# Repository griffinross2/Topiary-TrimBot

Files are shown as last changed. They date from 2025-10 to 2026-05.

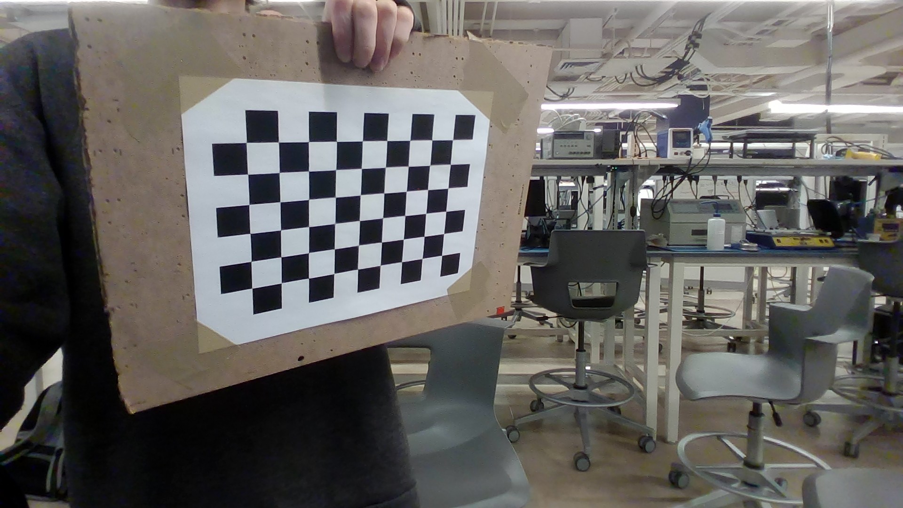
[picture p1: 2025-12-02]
experimental/cpp/plant_detect/images/WIN_20251111_21_14_00_Pro.jpg

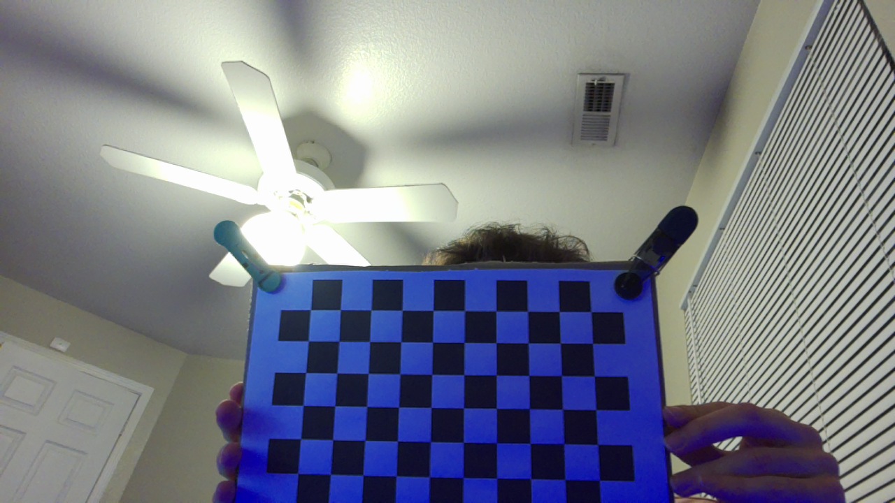
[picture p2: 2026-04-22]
experimental/cpp/plant_detect/images/pi/cal_10.jpg

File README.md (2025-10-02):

# Topiary TrimBot
Have you ever seen a sculpture made not of stone or ice, but a living, growing plant? Topiaries are a common feature of lavish gardens staffed by professional topiarists, but are often out-of-reach of the amateur gardener or homeowner. Enter the Topiary TrimBot, an automated platform for creating your own custom topiaries. A bush is placed in the machine and then the user inputs their desired 3D shape. The TrimBot will then automatically detect the current plant shape, generate a plan for trimming it into the desired shape, and perform the required cutting. The user can then practice maintaining and refining the shape via hand-trimming, helping them to learn the art of topiary!

This is the home of the Purdue University ECE 49595SD senior design group E11 in Fall 2025.

## Members
Griffin Ross - [GitHub](https://github.com/griffinross2) - [LinkedIn](https://www.linkedin.com/in/griffin-ross-eng/)

Thomas Schorer - [GitHub](https://github.com/ThomasSchorer) - [LinkedIn](https://www.linkedin.com/in/thomas-schorer/)

Jackson Duke - [GitHub](https://github.com/JDuke3) - [LinkedIn](https://www.linkedin.com/in/duke-jackson/)

Collin Shanks - [GitHub](https://github.com/collinshanks) - [LinkedIn](https://www.linkedin.com/in/collinshanks/)

## Documents
The docs/ folder contains documents grouped by category

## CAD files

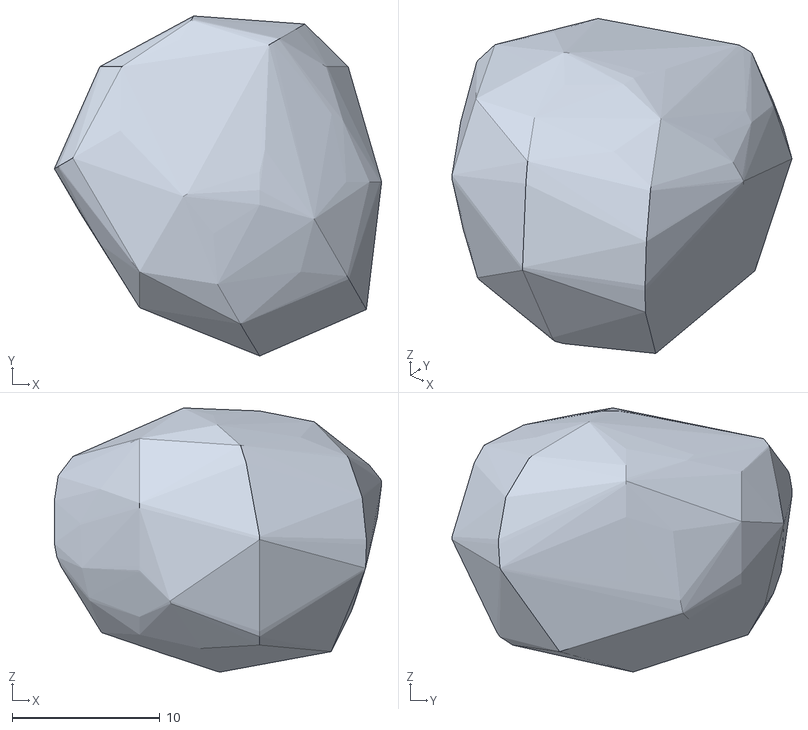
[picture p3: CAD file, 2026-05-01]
software/meshes/plant.ply
22.1 x 23.0 x 17.8

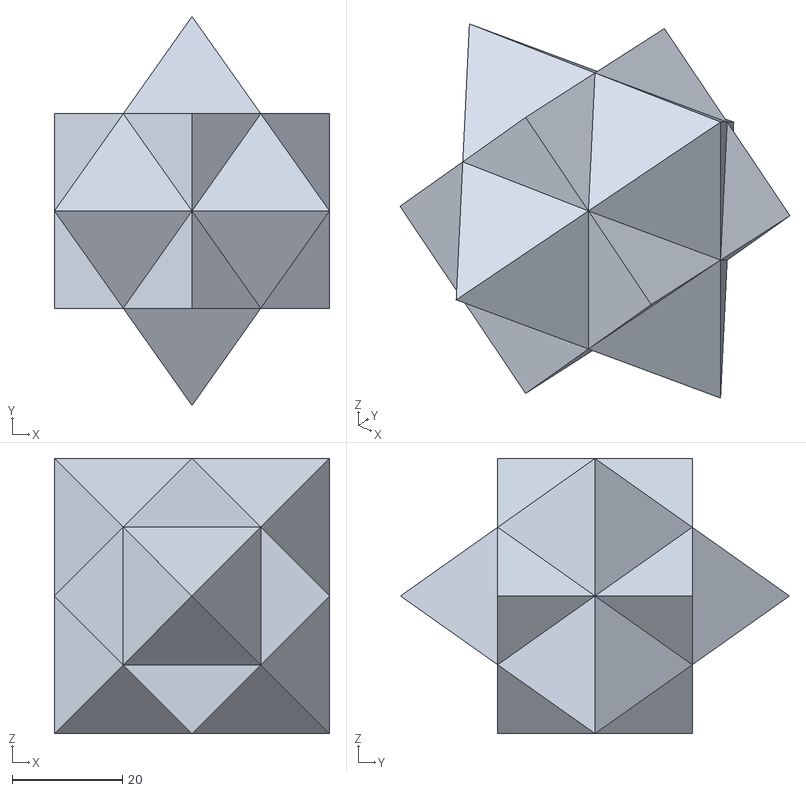
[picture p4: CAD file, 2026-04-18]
software/cube-octahedron-compound.stl
50.0 x 70.7 x 50.0

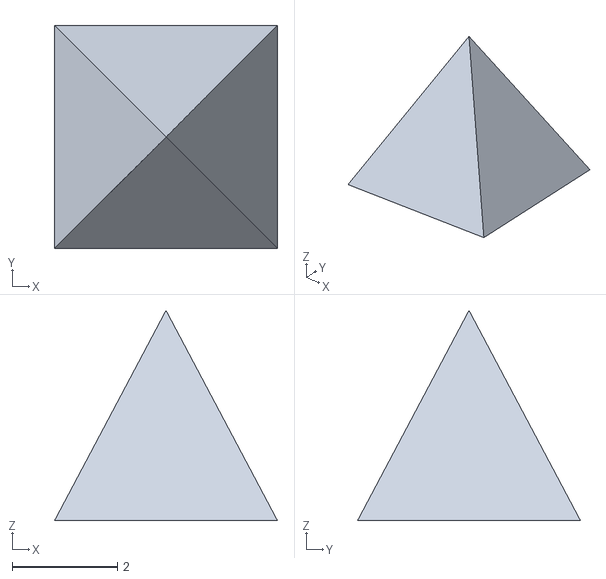
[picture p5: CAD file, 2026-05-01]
software/meshes/pyramid.stl
4.24 x 4.24 x 4.00

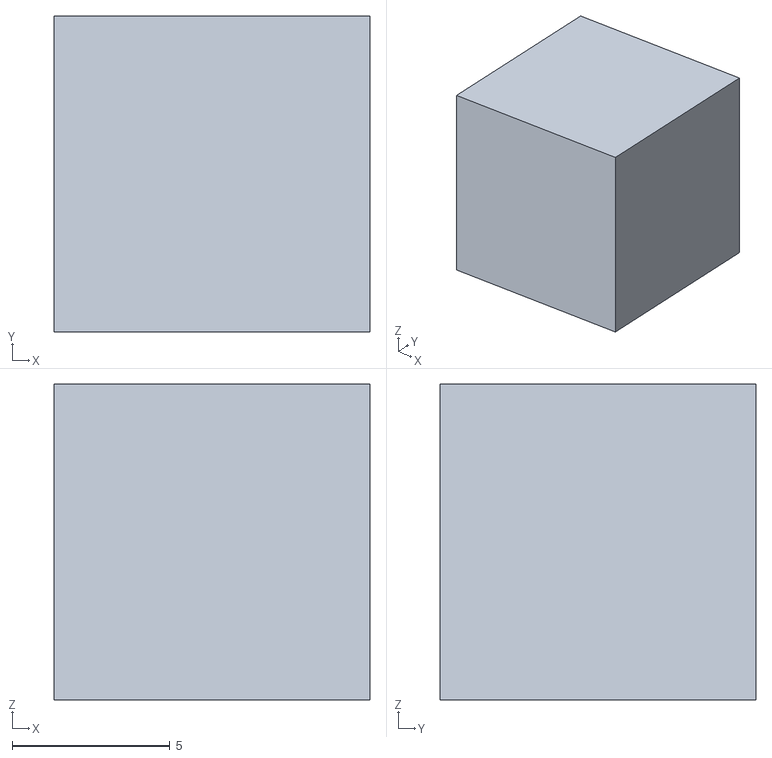
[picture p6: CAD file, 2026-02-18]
software/cube.obj
10.0 x 10.0 x 10.0

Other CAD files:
software/meshes/cube.obj

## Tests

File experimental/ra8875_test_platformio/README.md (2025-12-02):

# LCD Prototyping Project

This PlatformIO project is used to prototype LCD functionality on the STM32F469 Discovery Kit.

## How to use:

1. Install platformio on VSCode
2. Install python
3. Install STM Cube Programmer
4. Open the project in VSCode
5. In the root directory (with platformio.ini), add a script called `upload.bat` that will call STM Cube Programmer on the command line. 

## Upload.bat contents:

```
path/to/STM32_Programmer_CLI.exe -c port=SWD -el path/to/MT25QL128A_STM32F469I-DK.stldr" -d .pio/build/default/firmware.elf -rst
```

The path to STM32 Cube Programmer is usually: 

```
"C:\Program Files\STMicroelectronics\STM32Cube\STM32CubeProgrammer\bin\STM32_Programmer_CLI.exe"
```

and the path to the loader file is usually: 

```
"C:\Program Files\STMicroelectronics\STM32Cube\STM32CubeProgrammer\bin\ExternalLoader\MT25QL128A_STM32F469I-DK.stldr"
```

The second path is to an external loader file, which allows STM Cube Programmer to program external flash memories connected to the QSPI.

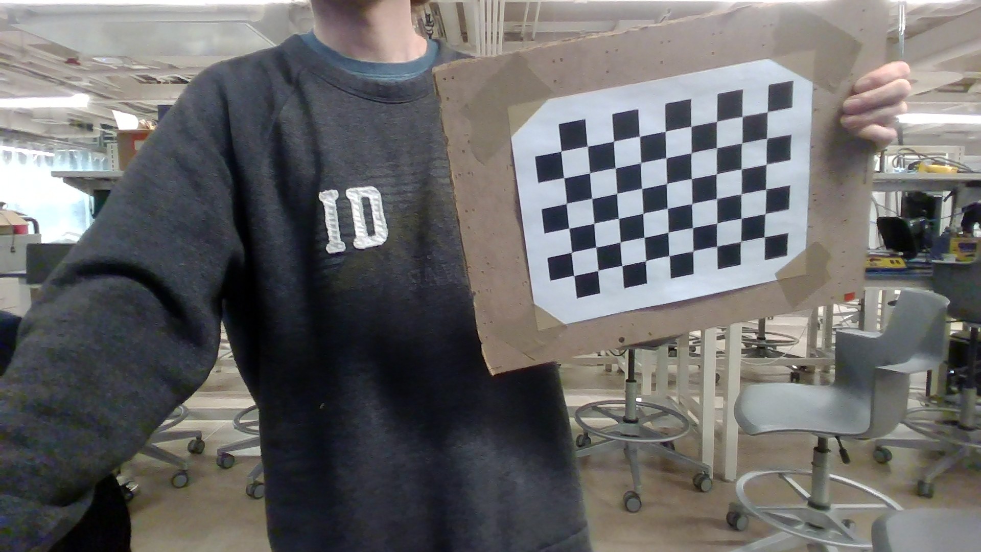
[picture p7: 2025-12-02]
experimental/cpp/plant_detect/images/WIN_20251111_21_15_00_Pro.jpg

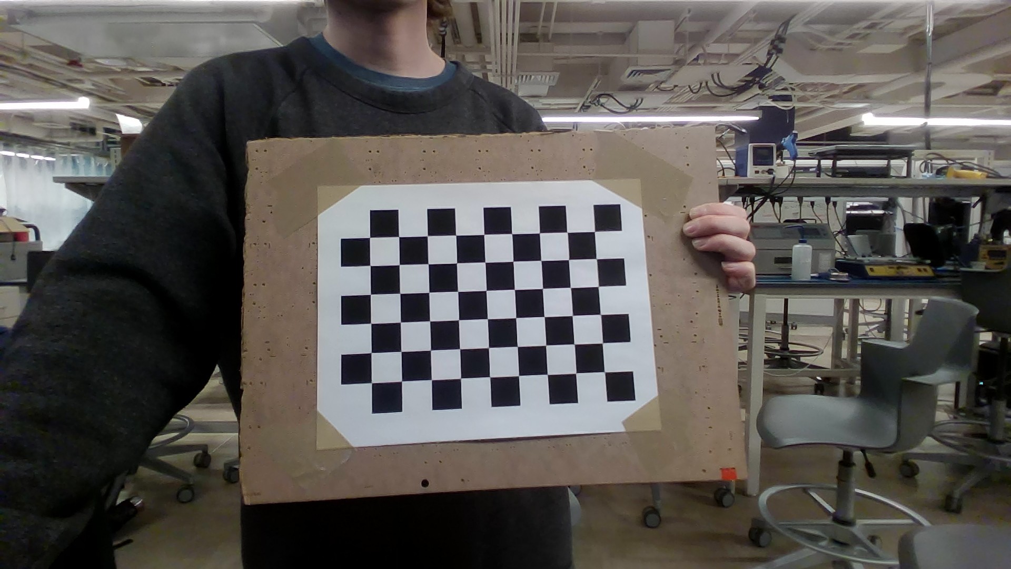
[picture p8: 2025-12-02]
experimental/cpp/plant_detect/images/WIN_20251111_21_15_03_Pro.jpg

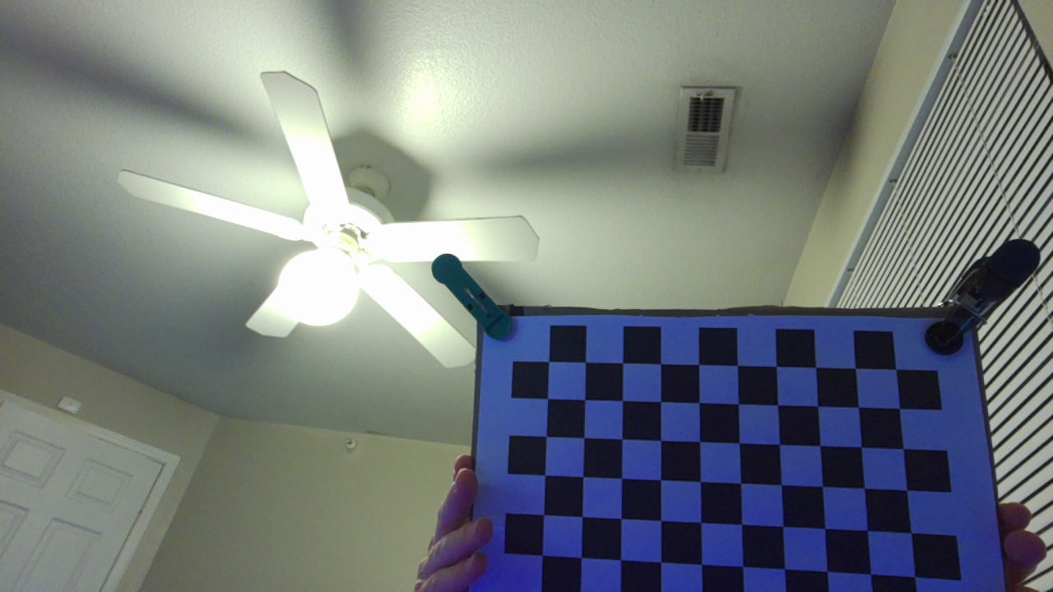
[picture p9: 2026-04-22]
experimental/cpp/plant_detect/images/pi/cal_9.jpg

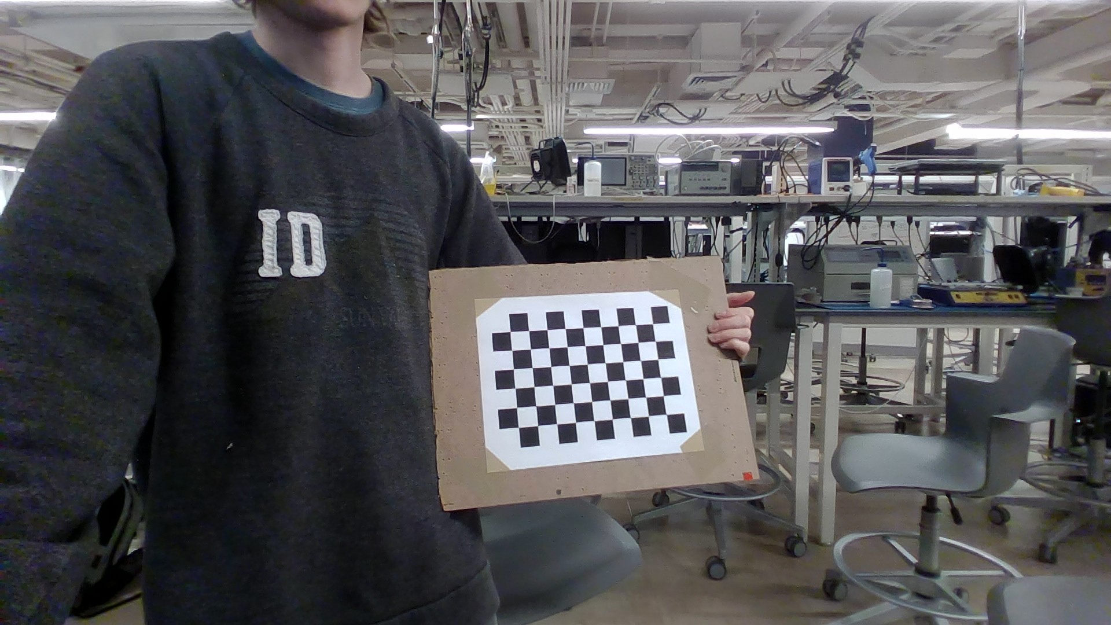
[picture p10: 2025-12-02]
experimental/cpp/plant_detect/images/WIN_20251111_21_14_32_Pro.jpg

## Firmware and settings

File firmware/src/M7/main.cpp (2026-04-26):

#include "stm32h7xx_hal.h"
#include "clocks.h"
#include "board.h"
#include "gpio/gpio.h"
#include "terminal.h"
#include "flash.h"
#include "sdmmc/sdmmc.h"
#include "ltdc.h"
#include "lcd.h"
#include "fonts/arial.h"
#include "images/blank.h"
#include "gui_app.h"
#include "filesystem.h"
#include "usb.h"
#include "profiler.h"
#include "packet_engine.h"
#include "pi_control.h"
#include "gcode_receiver.h"
#include "scheduler.h"

#include <stdio.h>

Status init();

int main(void) {
    // System initialization
    Status init_stat = init();
    while (init_stat != STATUS_OK) {
        gpio_toggle(PIN_RED);
        HAL_Delay(500);
    }

    // Scheduler setup
    scheduler_add_task("usb", usb_task, 10, 0);
    scheduler_add_task("packet_engine", packet_engine_task, 10, 1);
    scheduler_add_task("gcode_receiver", gcode_receiver_task, 100, 2);
    scheduler_add_task("filesystem", filesystem_task, 100, 3);
    scheduler_add_task("pi_control", pi_control_task, 100, 4);
    scheduler_add_task("gui_app", gui_app_task, 16, 5);

    // Also print the scheduler summary every 10 seconds
    scheduler_add_task("scheduler_summary", scheduler_print_summary, 10000,
                       100);

    // Main loop (just run the scheduler)
    while (1) {
        scheduler_run();
    }

    return 0;
}

/******************/
/* Init Functions */
/******************/

Status corem4_init() {
    HAL_RCCEx_EnableBootCore(RCC_BOOT_C2);
    return STATUS_OK;
}

void gpio_set_initial_state() {
    gpio_write(PIN_TURNTABLE_DIR, GPIO_HIGH);
    gpio_write(PIN_GANTRY_DIR, GPIO_HIGH);
    gpio_write(PIN_EXTRUDER_DIR, GPIO_HIGH);
    gpio_write(PIN_REVOLUTE_DIR, GPIO_HIGH);
}

Status init() {
    HAL_Init();

    int init_stat = STATUS_OK;
    init_stat |= clocks_init() << 0;
    gpio_set_initial_state();
    init_stat |= corem4_init() << 1;
    profiler_init();
    init_stat |= terminal_init() << 2;
    init_stat |= flash_init() << 3;
    init_stat |= filesystem_init() << 4;
    init_stat |= usb_init() << 5;
    init_stat |= lcd_init() << 6;
    init_stat |= gui_app_init() << 7;
    init_stat |= packet_engine_init() << 8;
    init_stat |= scheduler_init() << 9;

    // Give the LCD the status so it can report an error
    gui_app_init_status(init_stat);

    if (init_stat != STATUS_OK) {
        printf("Initialization failed with status: 0x%x\n", init_stat);
        return STATUS_ERROR;
    } else {
        printf("Initialization successful!\n");
    }

    return STATUS_OK;
}

/**********************/
/* Interrupt Handlers */
/**********************/

extern "C" {
void NMI_Handler(void);
void HardFault_Handler(void);
void MemManage_Handler(void);
void BusFault_Handler(void);
void UsageFault_Handler(void);
void SVC_Handler(void);
void DebugMon_Handler(void);
void PendSV_Handler(void);
void SysTick_Handler(void);
}

void NMI_Handler(void) {
    while (1) {
    }
}

void HardFault_Handler(void) {
    while (1) {
    }
}

void MemManage_Handler(void) {
    while (1) {
    }
}

void BusFault_Handler(void) {
    while (1) {
    }
}

void UsageFault_Handler(void) {
    while (1) {
    }
}

void SVC_Handler(void) {}

void DebugMon_Handler(void) {}

void PendSV_Handler(void) {}

void SysTick_Handler(void) {
    HAL_IncTick();
}

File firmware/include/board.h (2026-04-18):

/*
    Board specific definitions such as pin assignments
    From Purdue Space Program High Altitude, Original author: Griffin Ross
*/

#ifndef BOARD_H
#define BOARD_H

#include "stm32h7xx_hal.h"

// Port to index
#define PIN_PA0 0
#define PIN_PA1 1
#define PIN_PA2 2
#define PIN_PA3 3
#define PIN_PA4 4
#define PIN_PA5 5
#define PIN_PA6 6
#define PIN_PA7 7
#define PIN_PA8 8
#define PIN_PA9 9
#define PIN_PA10 10
#define PIN_PA11 11
#define PIN_PA12 12
#define PIN_PA13 13
#define PIN_PA14 14
#define PIN_PA15 15
#define PIN_PB0 16
#define PIN_PB1 17
#define PIN_PB2 18
#define PIN_PB3 19
#define PIN_PB4 20
#define PIN_PB5 21
#define PIN_PB6 22
#define PIN_PB7 23
#define PIN_PB8 24
#define PIN_PB9 25
#define PIN_PB10 26
#define PIN_PB11 27
#define PIN_PB12 28
#define PIN_PB13 29
#define PIN_PB14 30
#define PIN_PB15 31
#define PIN_PC0 32
#define PIN_PC1 33
#define PIN_PC2 34
#define PIN_PC3 35
#define PIN_PC4 36
#define PIN_PC5 37
#define PIN_PC6 38
#define PIN_PC7 39
#define PIN_PC8 40
#define PIN_PC9 41
#define PIN_PC10 42
#define PIN_PC11 43
#define PIN_PC12 44
#define PIN_PC13 45
#define PIN_PC14 46
#define PIN_PC15 47
#define PIN_PD0 48
#define PIN_PD1 49
#define PIN_PD2 50
#define PIN_PD3 51
#define PIN_PD4 52
#define PIN_PD5 53
#define PIN_PD6 54
#define PIN_PD7 55
#define PIN_PD8 56
#define PIN_PD9 57
#define PIN_PD10 58
#define PIN_PD11 59
#define PIN_PD12 60
#define PIN_PD13 61
#define PIN_PD14 62
#define PIN_PD15 63
#define PIN_PE0 64
#define PIN_PE1 65
#define PIN_PE2 66
#define PIN_PE3 67
#define PIN_PE4 68
#define PIN_PE5 69
#define PIN_PE6 70
#define PIN_PE7 71
#define PIN_PE8 72
#define PIN_PE9 73
#define PIN_PE10 74
#define PIN_PE11 75
#define PIN_PE12 76
#define PIN_PE13 77
#define PIN_PE14 78
#define PIN_PE15 79
#define PIN_PF0 80
#define PIN_PF1 81
#define PIN_PF2 82
#define PIN_PF3 83
#define PIN_PF4 84
#define PIN_PF5 85
#define PIN_PF6 86
#define PIN_PF7 87
#define PIN_PF8 88
#define PIN_PF9 89
#define PIN_PF10 90
#define PIN_PF11 91
#define PIN_PF12 92
#define PIN_PF13 93
#define PIN_PF14 94
#define PIN_PF15 95
#define PIN_PG0 96
#define PIN_PG1 97
#define PIN_PG2 98
#define PIN_PG3 99
#define PIN_PG4 100
#define PIN_PG5 101
#define PIN_PG6 102
#define PIN_PG7 103
#define PIN_PG8 104
#define PIN_PG9 105
#define PIN_PG10 106
#define PIN_PG11 107
#define PIN_PG12 108
#define PIN_PG13 109
#define PIN_PG14 110
#define PIN_PG15 111
#define PIN_PH0 112
#define PIN_PH1 113

#define PIN_MAX PIN_PK7

__attribute__((unused)) static GPIO_TypeDef* BOARD_GPIO_PORT[] = {
    GPIOA, GPIOB, GPIOC, GPIOD, GPIOE, GPIOF,
    GPIOG, GPIOH, GPIOI, GPIOJ, GPIOK};
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

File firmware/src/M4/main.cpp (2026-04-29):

#include "stm32h7xx_hal.h"
#include "marlin_wrapper.h"
#include "gpio/gpio.h"
#include "board.h"
#include "gcode/gcode.h"
#include "gcode/queue.h"
#include "module/planner.h"
#include "terminal.h"
#include "profiler.h"
#include "gcode_receiver.h"
#include "door_stop.h"
#include "pi_control.h"
#include "scheduler.h"

#include <stdio.h>

static void main_loop();
static void process_manual_gcode();
static void led_blink();

int main(void) {
    HAL_Init();

    // Disable cutter pin
    gpio_write(PIN_CUTTER, GPIO_LOW);

    profiler_init();

    int init_stat = 0;
    init_stat |= terminal_rx_start();
    init_stat |= door_stop_init();
    init_stat |= scheduler_init();

    scheduler_add_task("gcode_receiver", gcode_receiver_task, 100, 0);
    scheduler_add_task("pi_control", pi_control_task, 50, 1);
    scheduler_add_task("led_blink", led_blink, 1000, 2);
    scheduler_add_task("manual_gcode", process_manual_gcode, 100, 3);
    scheduler_add_task("scheduler_summary", scheduler_print_summary, 10000,
                       100);

    marlin_wrapper_init();

    // Marlin wrapper hosts the loop
    marlin_wrapper_set_idle_cb(main_loop);

    door_stop_task();

    // Delay before homing
    HAL_Delay(500);

    if (marlin_wrapper_is_alive()) {
        gcode.home_all_axes();
    } else {
        while (true) {
        }
    }

    queue.enqueue_one("G1 Z800");  // Move Z down

    marlin_wrapper_loop();

    return 0;
}

static void main_loop() {
    door_stop_task();
    scheduler_run();
}

static void process_manual_gcode() {
    static char s_manual_gcode_buf[64];
    static size_t s_manual_gcode_buf_len = 0;

    // Process manual g-code input
    int bytes_read =
        terminal_read((uint8_t*)(s_manual_gcode_buf + s_manual_gcode_buf_len),
                      sizeof(s_manual_gcode_buf) - 1 - s_manual_gcode_buf_len);
    if (bytes_read > 0) {
        if (s_manual_gcode_buf[s_manual_gcode_buf_len + bytes_read - 1] ==
            '\n') {
            s_manual_gcode_buf[s_manual_gcode_buf_len + bytes_read] = '\0';
            queue.enqueue_one(s_manual_gcode_buf);
            s_manual_gcode_buf_len = 0;
        } else {
            s_manual_gcode_buf_len += bytes_read;
        }
    }
}

static void led_blink() {
    gpio_toggle(PIN_BLU);
}

extern "C" {
void NMI_Handler(void);
void HardFault_Handler(void);
void MemManage_Handler(void);
void BusFault_Handler(void);
void UsageFault_Handler(void);
void SVC_Handler(void);
void DebugMon_Handler(void);
void PendSV_Handler(void);
void SysTick_Handler(void);
}

void NMI_Handler(void) {
    while (1) {
    }
}

void HardFault_Handler(void) {
    while (1) {
    }
}

void MemManage_Handler(void) {
    while (1) {
    }
}

void BusFault_Handler(void) {
    while (1) {
    }
}

void UsageFault_Handler(void) {
    while (1) {
    }
}

void SVC_Handler(void) {}

void DebugMon_Handler(void) {}

void PendSV_Handler(void) {}

void SysTick_Handler(void) {
    HAL_IncTick();
}

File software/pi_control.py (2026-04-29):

from packet import *
from usb import USBDev

currently_moving = False

def pi_control_give_packet(id: PacketID, data: bytes):
    from plant_scanning import start_scan
    from toolpathing import start_toolpathing
    from cutter import start_cutting
    global currently_moving
    
    match id.packet_type:
        case PACKET_TYPE_STATUS.packet_type:
            if len(data) == 1:
                currently_moving = int(data[0]) & 0x1 == 1
        
        case PACKET_TYPE_START_SCANNING.packet_type:
            start_scan()

        case PACKET_TYPE_START_TOOLPATHING.packet_type:
            start_toolpathing()

        case PACKET_TYPE_START_CUTTING.packet_type:
            start_cutting()

        case _:
            pass

def pi_control_is_moving():
    global currently_moving

    return currently_moving

def pi_control_send_booted(dev: USBDev):
    id = PACKET_TYPE_PI_BOOTED
    packet_send(dev, bytes(), id)

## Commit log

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2025-10-23 Plant detection: Solve performance issue by capturing video on separate thread
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2025-11-05 STM32F746 project for testing ethernet
    [stm32f746prototyping Debug.cfg]
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2025-11-14 Move stepper project to correct place and ignore build files
    [main.c, main.h, stepper_prototyping.ioc]
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2025-12-12 Initialize KiCad project, finally working touchscreen on LCD prototyping
    [TopiaryTrimbot.kicad_pcb, TopiaryTrimbot.kicad_sch]
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2026-01-13 LCD: working on video mode operation, KiCAD sheets
    [TopiaryTrimbot.kicad_sch, lcd.kicad_sch, mcu.kicad_sch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]
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2026-01-20 Schematic: Create lcd symbol and add to schematic
    [lcd.kicad_sch]
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2026-01-20 Missing changes in last commit
    [lcd.kicad_sch]
2026-01-21 LCD: Add in backlight driver, finish wiring
    [TopiaryTrimbot.kicad_sch, lcd.kicad_sch]
2026-01-21 Schematic: Symbols, wiring for storage
    [lcd.kicad_sch, storage.kicad_sch]
2026-01-21 Schematic - Added Buck ICs
    [power.kicad_sch]
2026-01-21 Custom power flag, lcd bug fix
    [lcd.cpp]
2026-01-21 Schematic - Power Flags
    [power.kicad_sch]
2026-01-21 Schematic: minor changes to lcd
    [TopiaryTrimbot.kicad_pcb, lcd.kicad_sch, storage.kicad_sch]
2026-01-21 Schematic: added TPS56837Hx symbol and footprint
    [lcd.kicad_sch]
2026-01-22 Schematic - Power flag
    [power.kicad_sch]
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2026-01-24 Schematic: Add global labels to storage
    [storage.kicad_sch]
2026-01-24 Schematic: fix lcd page issues
    [lcd.kicad_sch]
2026-01-26 Schematic: add test points to QSPI and SD buses
    [storage.kicad_sch]
2026-01-26 Schematic: Clearer top-level labels
    [TopiaryTrimbot.kicad_sch]
2026-01-28 Schematic - Motor Drivers
    [motor.kicad_sch]
2026-01-28 Schematic - Placed Correct 5-15 Buck IC
    [power.kicad_sch]
2026-01-28 Schematic - Placed Net Labels
    [motor.kicad_sch]
2026-01-28 Schematic - Driver Enable Jumpers
    [motor.kicad_sch]
2026-01-30 Schematic - Driver VDD Jumpers
    [motor.kicad_sch]
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2026-02-04 Update MCU
    Decoupling caps
    [mcu.kicad_sch]
2026-02-04 Schematic - Microstepping Jumpers
    [motor.kicad_sch]
2026-02-04 LCD schematic: added series resistors
    [lcd.kicad_sch]
2026-02-04 Schematic - 24 V Screw Terminal
    [power.kicad_sch]
2026-02-05 LCD schematic: new backlight circuit
    [lcd.kicad_sch]
2026-02-05 LCD Schematic: Remove random thing that was hangin around
    [lcd.kicad_sch]
2026-02-06 LCD schematic: small changes, add PSpice sim
    [lcd.kicad_sch]
2026-02-06 LCD schematic: small changes
    [lcd.kicad_sch]
2026-02-06 Update mcu
    redone decoupling caps
    [mcu.kicad_sch]
2026-02-06 LCD schematic: more small additions and set footprints for all components
    [lcd.kicad_sch]
2026-02-07 mcu and top level update
    more caps and mounting holes
    [TopiaryTrimbot.kicad_sch, mcu.kicad_sch]
2026-02-07 Schematic: add manufacturer PN field and start picking parts and footprints in LCD and Motor
    [lcd.kicad_sch, motor.kicad_sch]
2026-02-07 Schematic - Buck Converter Passives
    [power.kicad_sch]
2026-02-07 Schematic: change capacitor in backlight feedback according to sims, add oscillator symbol/footprint
    [lcd.kicad_sch]
2026-02-08 Update mcu.kicad_sch
    usb connector
    [mcu.kicad_sch]
2026-02-08 Add more symbols and continue filling footprints
    [lcd.kicad_sch, motor.kicad_sch, rpi.kicad_sch]
2026-02-08 Finished setting footprints for LCD, motors, RPi, and storage schematics
    [TopiaryTrimbot.kicad_sch, lcd.kicad_sch, motor.kicad_sch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]
2026-02-08 Update mcu.kicad_sch
    usb shield
    [mcu.kicad_sch]
2026-02-08 Touch up some ERC violations
    [TopiaryTrimbot.kicad_sch, lcd.kicad_sch, motor.kicad_sch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]
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2026-02-09 Update mcu.kicad_sch
    schematic almost ready
    [mcu.kicad_sch]
2026-02-10 Filling in more MCU details
    [mcu.kicad_sch]
2026-02-10 Add footprint for switch and wrap up footprint assignments for MCU
    [TopiaryTrimbot.kicad_sch, mcu.kicad_sch]
2026-02-11 MCU schematic: add debugging LEDs and no-connects
    [mcu.kicad_sch]
2026-02-11 Schematic - Power Components
    [power.kicad_sch]
2026-02-11 Schematic - Driver Fault LEDs
    [motor.kicad_sch]
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2026-02-11 Schematic - 24V fan & Driver Test Points
    [motor.kicad_sch, power.kicad_sch]
2026-02-11 Schematic - Motor Control Error
    [motor.kicad_sch, power.kicad_sch]
2026-02-11 Update mcu.kicad_sch
    test points
    [mcu.kicad_sch]
2026-02-11 Add ESD protection to SD card slot
    [storage.kicad_sch]
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2026-02-12 Schematic - Power Footprints
    [power.kicad_sch]
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2026-02-12 Schematic - Power Components and Footprints
    [power.kicad_sch]
2026-02-12 Schematic - New Power Modules
    [power.kicad_sch]
2026-02-12 Synchronized schematic draft and reannotated all
    [lcd.kicad_sch, mcu.kicad_sch, motor.kicad_sch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]
2026-02-12 Add components to PCB, fix some ERC violations
    [TopiaryTrimbot.kicad_pcb, power.kicad_sch]
2026-02-13 Finish first pass placement of parts on PCB, several updates and fixes to schematic included
    [TopiaryTrimbot.kicad_pcb, lcd.kicad_sch, mcu.kicad_sch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]
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2026-02-15 Update mcu.kicad_sch
    cap and led pns
    [mcu.kicad_sch]
2026-02-15 Continue layout, including swapping to linear BL driver
    [lcd.kicad_sch, mcu.kicad_sch, motor.kicad_sch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]
2026-02-15 all part numbers
    may need revisions
    [TopiaryTrimbot.kicad_sch, lcd.kicad_sch, mcu.kicad_sch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]
2026-02-15 Final changes before submission to website
    [TopiaryTrimbot.kicad_sch, mcu.kicad_sch, power.kicad_sch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]
2026-02-15 Fix datasheet reference
    [mcu.kicad_sch]
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2026-02-18 Start toolpathing development in python
    [cube.obj]
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2026-02-22 File sender/receiver implementation using packet system
    - Mirror image file sender and receiver state machines on the STM and PC implementations send file chunk by chunk until finished.
    - Still needs ability for receiver to request retransmission of packets after end ack.
    - Still needs timeouts/retransmission attempts on packets requiring ack to avoid hanging.
    - Needs more rigorous testing of edge cases.
    [board.h, clocks.cpp, gpio.cpp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]
2026-02-25 Exchange MEM2052 slot for MEM2090
    [storage.kicad_sch]
2026-02-27 Small fixes for stepper drivers plus support for MP6603
    [mcu.kicad_sch, motor.kicad_sch]
2026-02-28 Add cutting motor flyback diode and swap flash memory part for MX25L51245
    [motor.kicad_sch, storage.kicad_sch]
2026-03-03 Some more PCB updates based on CDR feedback
    Better perpendicular routing for LCD, remove testpoints on flash, add protection diodes for steppers
    [motor.kicad_sch, storage.kicad_sch]
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2026-03-05 Add -Wall -Wextra -Werror and fix all warnings/errors
    [clocks.cpp, lcd.cpp, sdmmc.cpp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]
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2026-03-25 MCU LED fix
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2026-03-27 Add I2C driver, fix various warnings
    [clocks.cpp, gpio.cpp, i2c.cpp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]
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2026-03-29 Fix TSC2013 init bug
    [i2c.cpp, lcd.cpp, main.cpp]
2026-03-30 Fix external loader issue
    [Loader_Src.c, flash.c, flash.cpp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]
2026-03-30 Touch detection working, EL still has sector erase issues
    [main.cpp, tsc2013.cpp]
2026-03-30 Fix some remaining flash bugs
    [flash.c, flash.cpp, lcd.cpp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]
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2026-04-02 Fix both cores using RAM_D2, change to polling for touchscreen
    [main.cpp, tsc2013.cpp]
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2026-04-03 Trying to fix SHIT ASS debugger
    [clocks.cpp, main.cpp, marlin_wrapper.cpp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]
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2026-04-10 Minor firmware fixes/changes made while testing the gantry
    [marlin_wrapper.cpp]
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2026-04-14 Fix reinstantiating file list objects every update
    [gui_app.cpp]
2026-04-14 Add more GUI pages (file sending, file error, begin scanning)
    [gui_app.cpp]
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2026-04-14 Python version of the USB packet program on Pi
    [cube.obj]
2026-04-15 Marlin configuration changes for homing test
    - Invert all axes (apparently needs this not to do the weird backwards movement before homing movement)
    - Set extruders to 0 and final axes assignments as X: turntable, Y: extruder, Z: gantry, I: wrist/revolute
    - Set steps/mm and feedrate: currently appropriate speeds for turntable, gantry, and extruder. Additionally gantry steps/mm was measured and set properly, with a roughly 1mm accuracy over the ~813mm total travel.
    - Note: the Z axis finishes its homing backed off a few mm from the endstop. This is expected, as telling it to go to 0mm will just put it back on the endstop.
    - Note: The wrist/revolute joint is currently set not to home. Need to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
    [board.h, gui_app.cpp, main.cpp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]
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2026-04-16 Toolpathing iteration is almost there except annoying issue with the keepout zone
    [new_mesh.ply, surf.ply, surf.stl]
2026-04-18 Finalize axes for Marlin, calibrate steps/unit, more toolpathing script bs
    [surf.ply]
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2026-04-21 Firmware changes to support scanning sequence and fix packet bugs
    [gui_app.cpp, main.cpp, terminal.cpp]
2026-04-21 depth correction case
    [plant.ply]
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2026-04-22 Angle sweep on toolpathing and encapsulate it all as a function
    [mesh.ply]
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2026-04-22 Finally working cross section (static)
    - Still a weird issue where one segment of the plant is missing
    [gui_app.cpp, lcd.cpp, main.cpp]
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2026-04-23 Fix many bugs and get working scanning and mostly working toolpathing
    [plant.ply]
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2026-04-25 Update tinyusb to hopefully fix crashing
    [tusb_config.h]
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2026-04-25 Fix kinematic model bug
    [main.cpp]
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2026-04-26 Fix calibration script
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2026-04-29 Fix M4 and scheduler bugs, update Pi to wait for post scanning rest point before sending done
    [door_stop.cpp, main.cpp]
2026-04-29 Fix some more Pi stuff
    [create_slices.py, file_receiver.py, gcode_sender.py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]
2026-04-29 Random fixes to pi
    [plant.ply]
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2026-04-30 emergency gcode fix
    [plant.ply]
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2026-05-01 Fix plant cutoff by adding padding to images
    [plant.ply]
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2026-05-01 Fix slice rotation issue in plant scanning
    [plant.ply]
